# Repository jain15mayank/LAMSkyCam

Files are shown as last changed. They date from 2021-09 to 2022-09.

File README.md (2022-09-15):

# LAMSkyCam: A Low-cost and Miniature Ground-based Sky Camera

With the spirit of reproducible research, this repository contains all the codes and materials required to make the hardware in the manuscript:

> Jain, M., Sengar, V. S., Gollini, I., Bertolotto, M., McArdle, G., and Dev, S.(2022). LAMSkyCam: A Low-cost and Miniature Ground-based Sky Camera. In: HardwareX, 2022.

Please cite the above paper if you intend to use whole/part of the code. This code is only for academic and research purposes.

## Manuscript
The manuscript can be accessed from [this](https://arxiv.org/pdf/2209.06051.pdf) link.

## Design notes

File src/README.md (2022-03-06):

This folder contains the source code to manage external memory and capture images from the camera. Other aspects like maintaining the running status of `manageHDD_cron.py` and executing `cameraSave_cron.py` at regular intervals is managed by adding cronjobs in RaspberryPi OS.

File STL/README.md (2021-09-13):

This directory contains the STL files for rapid prototyping of the existing design of the WSI.

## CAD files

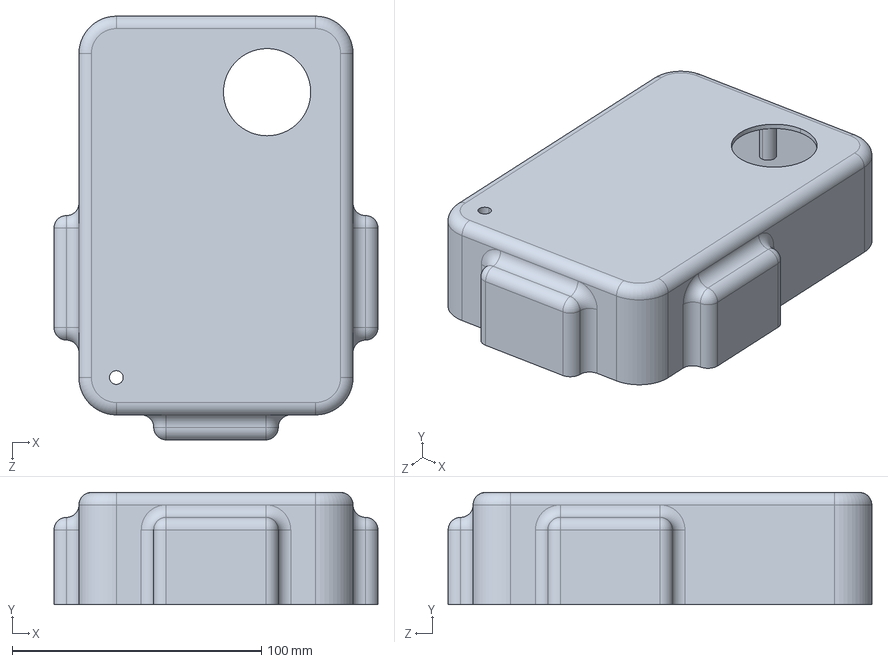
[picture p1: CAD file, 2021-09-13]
STEP/Part #01.STEP
130.0 x 45.0 x 170.0 mm

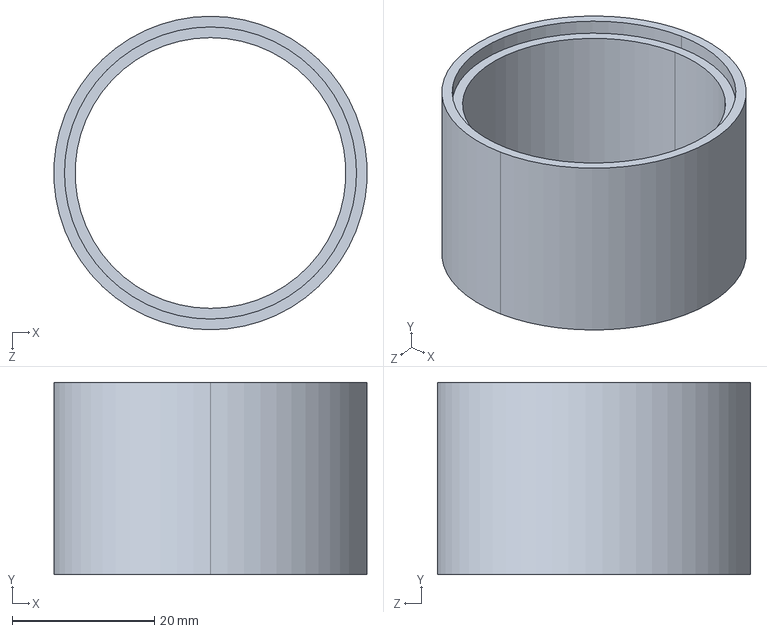
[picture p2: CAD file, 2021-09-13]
STEP/Part #07.STEP
43.9 x 27.0 x 44.0 mm

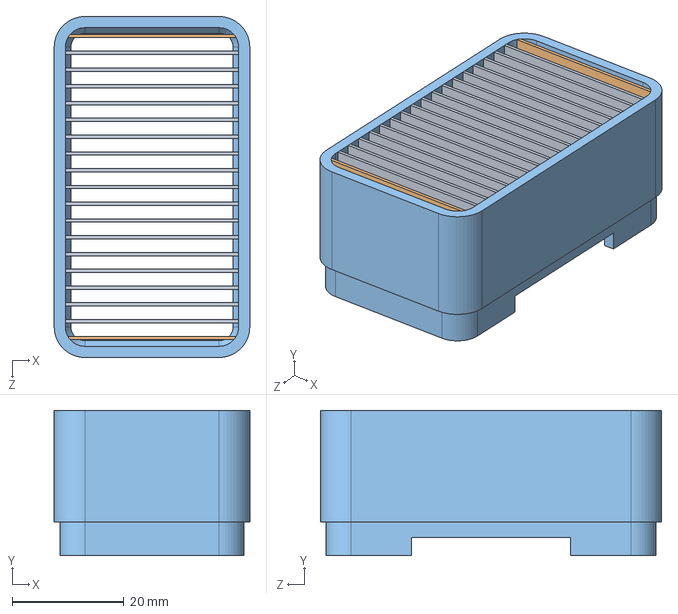
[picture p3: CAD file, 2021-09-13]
STEP/Part #03.STEP
35.0 x 26.0 x 61.0 mm

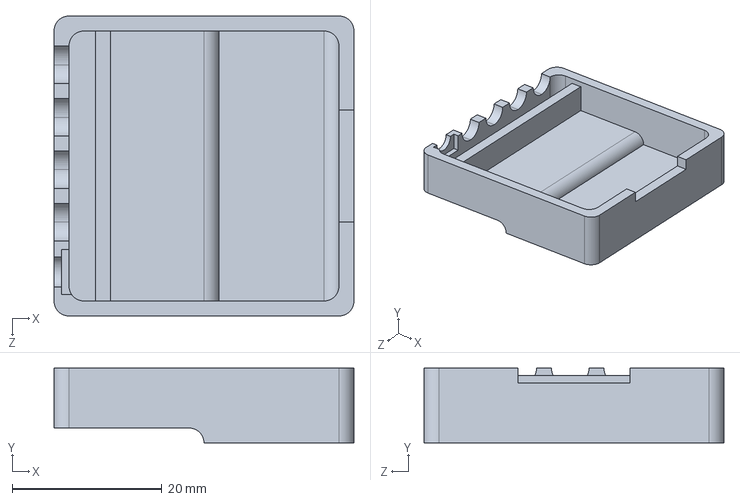
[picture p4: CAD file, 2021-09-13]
STEP/Part #09.STEP
40.0 x 10.0 x 40.0 mm

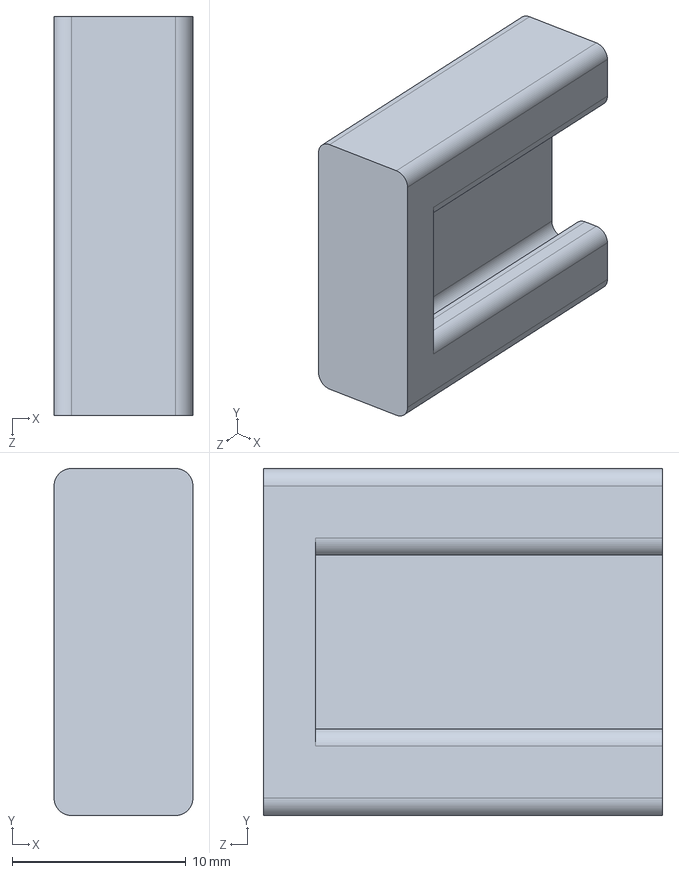
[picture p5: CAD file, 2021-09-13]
STEP/Part #05.STEP
8.00 x 20.0 x 23.0 mm

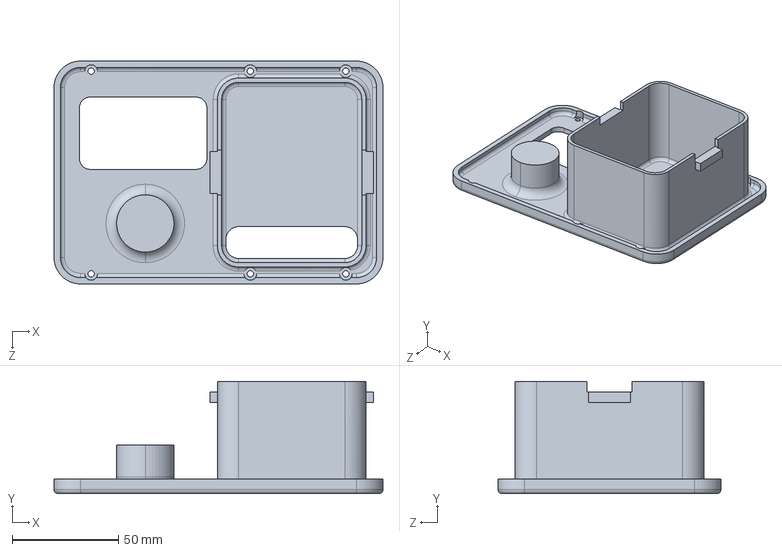
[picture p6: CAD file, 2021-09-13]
STEP/Part #02.STEP
155.0 x 53.0 x 105.0 mm

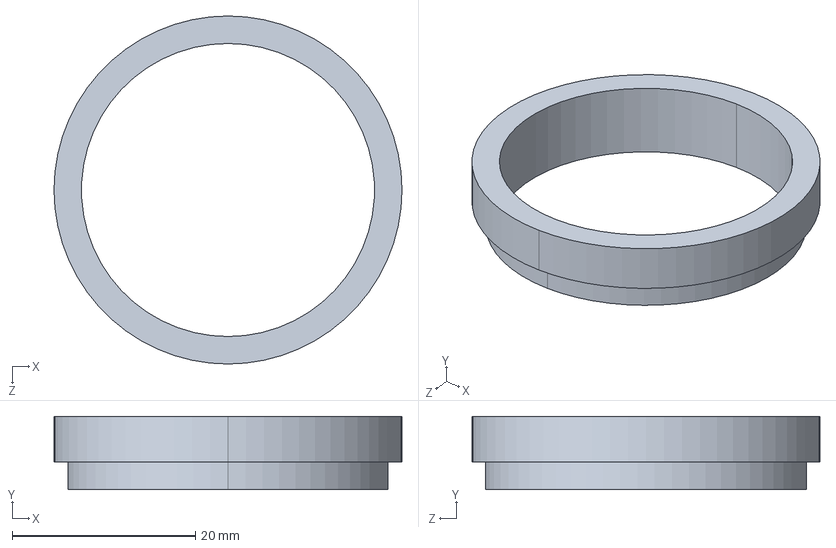
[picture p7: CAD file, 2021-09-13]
STEP/Part #06.STEP
38.0 x 8.00 x 38.0 mm

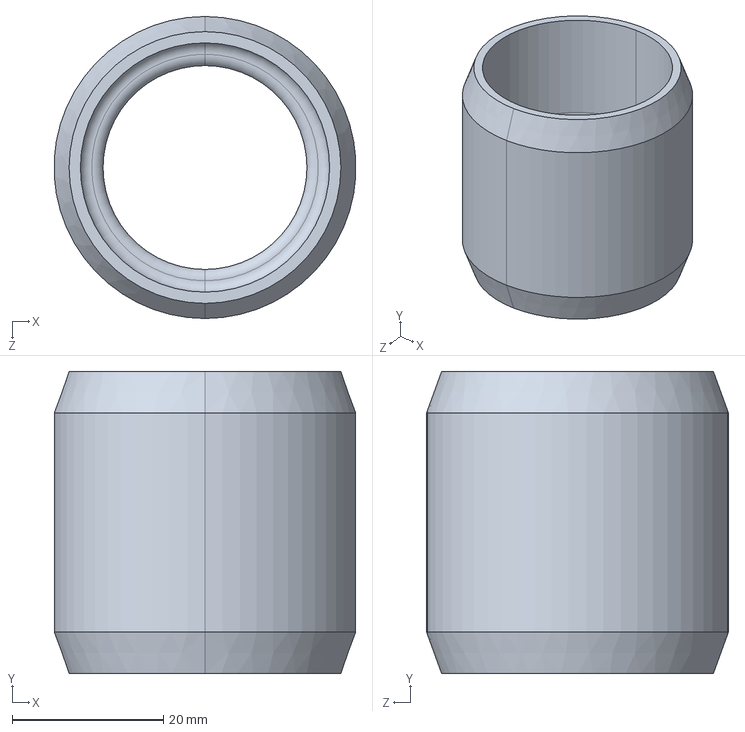
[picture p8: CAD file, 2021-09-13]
STEP/Part #11.STEP
39.9 x 40.0 x 40.0 mm

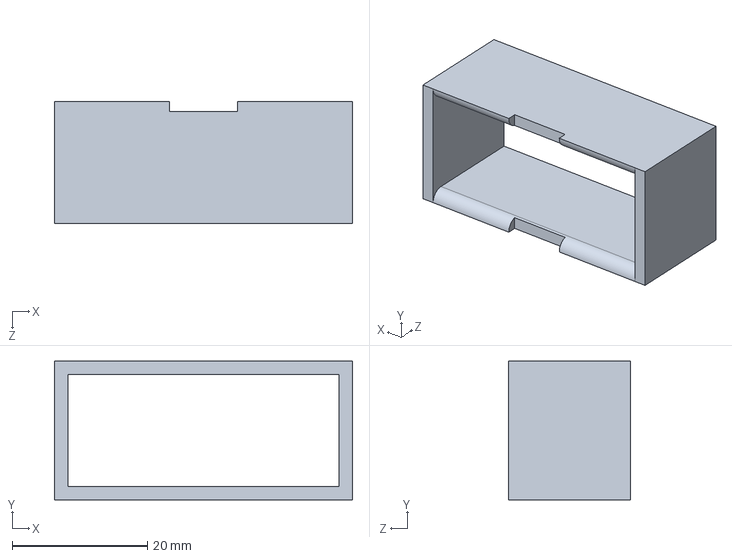
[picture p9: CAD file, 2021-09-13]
STEP/Part #10.STEP
44.0 x 20.5 x 18.0 mm

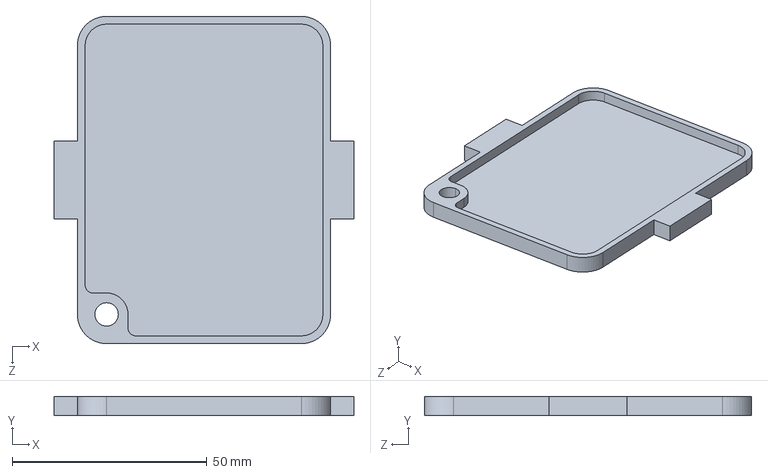
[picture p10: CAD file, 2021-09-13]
STEP/Part #04.STEP
77.0 x 5.00 x 84.0 mm

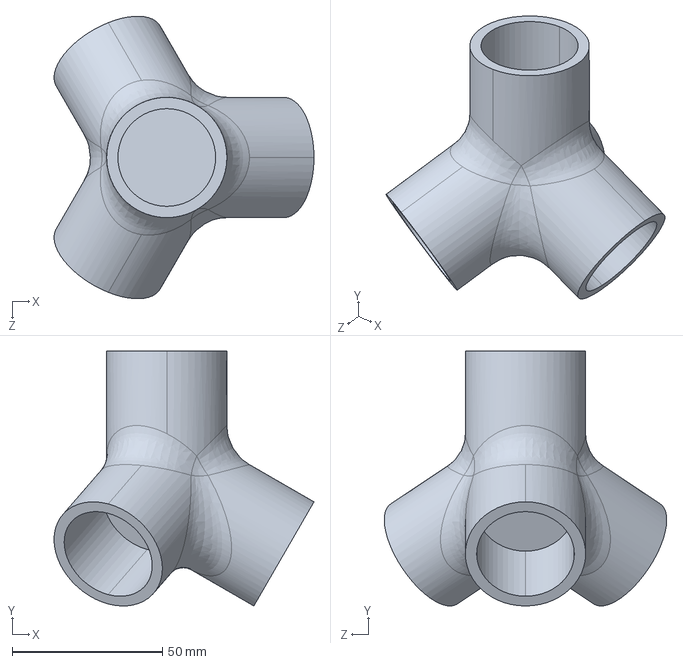
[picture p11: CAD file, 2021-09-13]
STEP/Part #12.STEP
86.5 x 84.8 x 93.9 mm

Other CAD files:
STEP/Part #08.STEP
STL/Part #01.STL
STL/Part #02.STL
STL/Part #03.STL
STL/Part #04.STL
STL/Part #05.STL
STL/Part #06.STL
STL/Part #07.STL
STL/Part #08.STL
STL/Part #09.STL
STL/Part #10.STL
STL/Part #11.STL
STL/Part #12.STL

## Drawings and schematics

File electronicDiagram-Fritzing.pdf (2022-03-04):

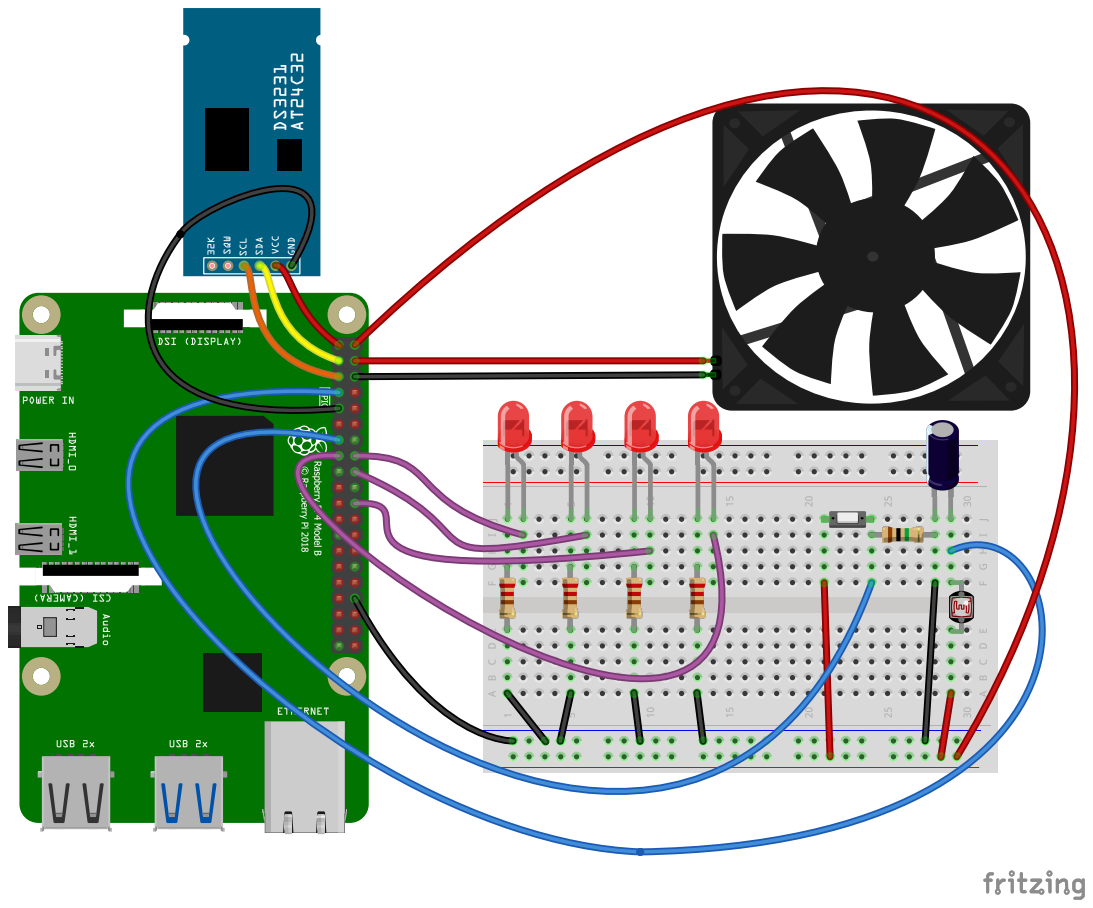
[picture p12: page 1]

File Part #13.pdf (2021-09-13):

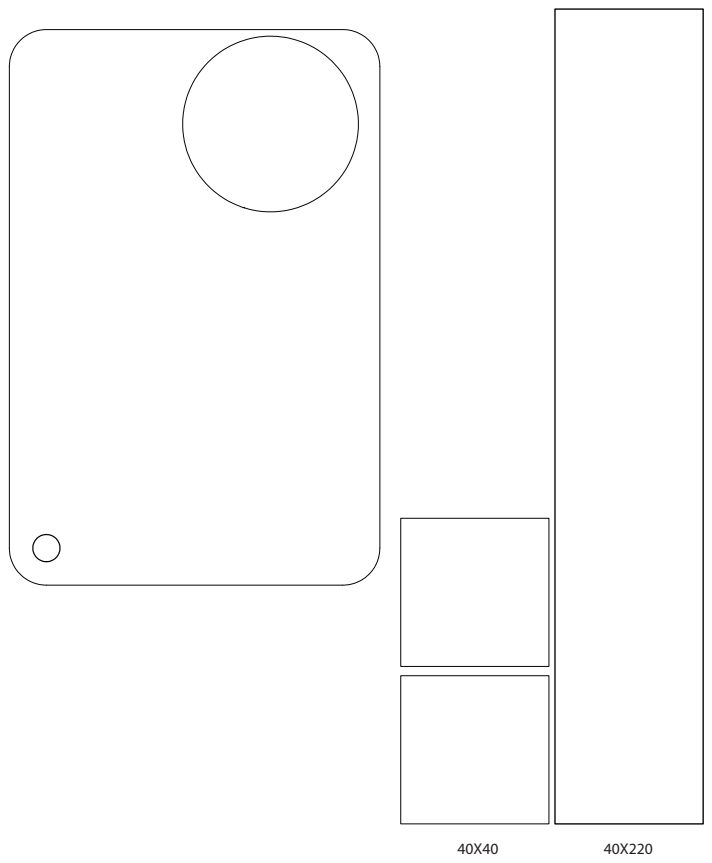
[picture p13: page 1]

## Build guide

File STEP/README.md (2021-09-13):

This directory contains the design files in STEP (ISO 10303) format for easy reproducibility and customization. All the parts have been individually discussed in detail in the published manuscript.

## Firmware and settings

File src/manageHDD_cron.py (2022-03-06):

#!/usr/bin/env python3

import os
import subprocess
import RPi.GPIO as GPIO    # Import Raspberry Pi GPIO library
from time import time, localtime, sleep
from utils import checkHDDstatus
from utils import SD2HD

# Determine the PID of current process
pid = str(os.getpid())
# Define path to the pidfile
pidfile = '/tmp/WSI_HDD_daemon.pid'
# Write the PID to that file
f = open(pidfile, "w")
f.write(pid)
f.close()

# Label/Name of the Hard disk where final data will be stored
HDlabel = 'Seagate Expansion Drive'

# Path where images will be stored
imageDirHD = '/media/pi/'+HDlabel+'/Mayank/WSI/images/'
imageDirSD = '/home/pi/Pictures/'

logsHDDpath = '/home/pi/Desktop/WSIwork/HDDlogs'

log_time = localtime(time())
timeSTR = str(log_time.tm_year)+'/' + \
          str(log_time.tm_mon)+'/' + \
          str(log_time.tm_mday)+' ' + \
          str(log_time.tm_hour)+':' + \
          str(log_time.tm_min)+':' + \
          str(log_time.tm_sec)
logsHDD = open(logsHDDpath, 'a')
logsHDD.write(timeSTR + " - HDD File started with PID: " + pid + "\n")
logsHDD.close()

GPIO.setwarnings(False)    # Ignore warnings for now
GPIO.setmode(GPIO.BCM)     # Use GPIO pin numbering

# Declare Peripherals
LED1 = 22 # Button Press Detected
LED2 = 23 # Removing Hard Disk Completed
LED3 = 24 # Hard Disk detected Once Again
LED4 = 25 # Writing data to disk - notification LED
PBut = 27

# Set all LEDs to OUTPUT and initialize to LOW
GPIO.setup(LED1, GPIO.OUT, initial=GPIO.LOW)
GPIO.setup(LED2, GPIO.OUT, initial=GPIO.LOW)
GPIO.setup(LED3, GPIO.OUT, initial=GPIO.LOW)
GPIO.setup(LED4, GPIO.OUT, initial=GPIO.LOW)
# Set Push Button to INPUT
GPIO.setup(PBut, GPIO.IN)

# Define Unmount Flag :: True = HDD unmounted; False = HDD mounted
if checkHDDstatus(HDlabel): # HDD is mounted
    isUnmounted = False
    log_time = localtime(time())
    timeSTR = str(log_time.tm_year)+'/' + \
              str(log_time.tm_mon)+'/' + \
              str(log_time.tm_mday)+' ' + \
              str(log_time.tm_hour)+':' + \
              str(log_time.tm_min)+':' + \
              str(log_time.tm_sec)
    logsHDD = open(logsHDDpath, 'a')
    logsHDD.write(timeSTR + " - HDD is detected INITIALLY!\n")
    logsHDD.close()
else:
    isUnmounted = True
    log_time = localtime(time())
    timeSTR = str(log_time.tm_year)+'/' + \
              str(log_time.tm_mon)+'/' + \
              str(log_time.tm_mday)+' ' + \
              str(log_time.tm_hour)+':' + \
              str(log_time.tm_min)+':' + \
              str(log_time.tm_sec)
    logsHDD = open(logsHDDpath, 'a')
    logsHDD.write(timeSTR + " - HDD is NOT detected INITIALLY!\n")
    logsHDD.close()

# Define Callback for Push Button Interrupt
def button_pressed(channel):
    global isUnmounted
    print('Button Pressed!!')
    log_time = localtime(time())
    timeSTR = str(log_time.tm_year)+'/' + \
              str(log_time.tm_mon)+'/' + \
              str(log_time.tm_mday)+' ' + \
              str(log_time.tm_hour)+':' + \
              str(log_time.tm_min)+':' + \
              str(log_time.tm_sec)
    logsHDD = open(logsHDDpath, 'a')
    logsHDD.write(timeSTR + " - Button Press Detected\n")
    logsHDD.close()
    # Turn on to indicate detection button press
    GPIO.output(LED1, GPIO.HIGH)
    if checkHDDstatus(HDlabel): # HDD is mounted
        subprocess.call("sudo umount -t fuseblk /dev/sda1", shell=True)
        isUnmounted = True
        # Turn on to indicate successful unmount
        GPIO.output(LED2, GPIO.HIGH)
        sleep(5)
        GPIO.output(LED2, GPIO.LOW)
        sleep(1)
    GPIO.output(LED1, GPIO.LOW)
    log_time = localtime(time())
    timeSTR = str(log_time.tm_year)+'/' + \
              str(log_time.tm_mon)+'/' + \
              str(log_time.tm_mday)+' ' + \
              str(log_time.tm_hour)+':' + \
              str(log_time.tm_min)+':' + \
              str(log_time.tm_sec)
    logsHDD = open(logsHDDpath, 'a')
    logsHDD.write(timeSTR + " - HDD Unmounting routine successful!\n")
    logsHDD.close()

# Define event of pressing Push Button as Interrupt (debounce time in ms)
GPIO.add_event_detect(PBut, GPIO.RISING,\
                      callback = button_pressed, bouncetime = 10000)

# Main Code Statrts Here
prevHr = localtime(time()).tm_hour
while True: # Run Forever
    currHr = localtime(time()).tm_hour
    if (not currHr == prevHr) and (currHr == 0 or currHr==12) and (not isUnmounted):
        log_time = localtime(time())
        timeSTR = str(log_time.tm_year)+'/' + \
                  str(log_time.tm_mon)+'/' + \
                  str(log_time.tm_mday)+' ' + \
                  str(log_time.tm_hour)+':' + \
                  str(log_time.tm_min)+':' + \
                  str(log_time.tm_sec)
        logsHDD = open(logsHDDpath, 'a')
        logsHDD.write(timeSTR + " - Conditions for Writing Data MET - Writing to HDD...\n")
        logsHDD.close()
        # Begin transferring data to HDD
        GPIO.output(LED4, GPIO.HIGH)
        SD2HD(imageDirSD, imageDirHD)
        GPIO.output(LED4, GPIO.LOW)
        # End transferring data to HDD
        log_time = localtime(time())
        timeSTR = str(log_time.tm_year)+'/' + \
                  str(log_time.tm_mon)+'/' + \
                  str(log_time.tm_mday)+' ' + \
                  str(log_time.tm_hour)+':' + \
                  str(log_time.tm_min)+':' + \
                  str(log_time.tm_sec)
        logsHDD = open(logsHDDpath, 'a')
        logsHDD.write(timeSTR + " - Writing to HDD successful!\n")
        logsHDD.close()
        prevHr = currHr
    else:
        temp = localtime(time()).tm_hour
        if not (temp==0 or temp==12):
            prevHr = temp
        if checkHDDstatus(HDlabel) and isUnmounted:
            log_time = localtime(time())
            timeSTR = str(log_time.tm_year)+'/' + \
                      str(log_time.tm_mon)+'/' + \
                      str(log_time.tm_mday)+' ' + \
                      str(log_time.tm_hour)+':' + \
                      str(log_time.tm_min)+':' + \
                      str(log_time.tm_sec)
            logsHDD = open(logsHDDpath, 'a')
            logsHDD.write(timeSTR + " - HDD Redected!\n")
            logsHDD.close()
            isUnmounted = False
            # Turn on LED3 for 5 seconds to indicate HDD detection
            GPIO.output(LED3, GPIO.HIGH)
            sleep(5)
            GPIO.output(LED3, GPIO.LOW)

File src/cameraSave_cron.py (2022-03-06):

#!/usr/bin/env python3

from utils import captureNsave
import RPi.GPIO as GPIO
from time import sleep, time, localtime
import subprocess
from pathlib import Path

GPIO.setwarnings(False)    # Ignore warnings for now
GPIO.setmode(GPIO.BCM)     # Use GPIO pin numbering

# Declare Peripherals
LDR = 4 # LDR Connected Here

imageDirSD = '/home/pi/Pictures/'

# Function to check LDR Reading
def rc_time (pin_to_circuit):
    for i in range(5):
        count = 0
        
        #Output LOW on the pin for 0.1 seconds
        GPIO.setup(pin_to_circuit, GPIO.OUT)
        GPIO.output(pin_to_circuit, GPIO.LOW)
        sleep(0.1)
        
        #Change the pin back to input
        GPIO.setup(pin_to_circuit, GPIO.IN)
      
        #Count until the pin goes high
        while (GPIO.input(pin_to_circuit) == GPIO.LOW):
            count += 1
        sleep(0.1)
    
    return count/5

curr_time = localtime(time())
timeSTR = str(curr_time.tm_year)+'/' + \
          str(curr_time.tm_mon)+'/' + \
          str(curr_time.tm_mday)+' ' + \
          str(curr_time.tm_hour)+':' + \
          str(curr_time.tm_min)+':' + \
          str(curr_time.tm_sec)
fLogs = open("/home/pi/Desktop/WSIwork/logs", "a")
fLogs.write(timeSTR + " - Capture Begin...\n")
fLogs.close()

imagePath = imageDirSD + str(curr_time.tm_year)+'/' + \
            str(curr_time.tm_mon)+'/' + \
            str(curr_time.tm_mday)+'/'
hh = "{0:0=2d}".format(curr_time.tm_hour)
mm = "{0:0=2d}".format(curr_time.tm_min)
ss = "{0:0=2d}".format(curr_time.tm_sec)
Path(imagePath).mkdir(parents=True, exist_ok=True)
#if curr_time.tm_hour>=19 or curr_time.tm_hour<5:
rcTime = rc_time(LDR)
curr_time = localtime(time())
timeSTR = str(curr_time.tm_year)+'/' + \
          str(curr_time.tm_mon)+'/' + \
          str(curr_time.tm_mday)+' ' + \
          str(curr_time.tm_hour)+':' + \
          str(curr_time.tm_min)+':' + \
          str(curr_time.tm_sec)
fLogs = open("/home/pi/Desktop/WSIwork/logs", "a")
fLogs.write(timeSTR + " - Value of rcTime is " + str(rcTime) + "\n")
fLogs.close()
if rcTime>100:
    subprocess.call("raspistill -md 3 -drc high -ex night -ss 2500000 -o " +imagePath+hh+mm+ss+".png", shell=True)
elif rcTime<50:
    subprocess.call("raspistill -md 3 -o " +imagePath+hh+mm+ss+".png", shell=True)
else:
    subprocess.call("raspistill -md 3 -drc med -ex night -ss 1500000 -o " +imagePath+hh+mm+ss+".png", shell=True)
#captureNsave(imageDirSD)

curr_time = localtime(time())
timeSTR = str(curr_time.tm_year)+'/' + \
          str(curr_time.tm_mon)+'/' + \
          str(curr_time.tm_mday)+' ' + \
          str(curr_time.tm_hour)+':' + \
          str(curr_time.tm_min)+':' + \
          str(curr_time.tm_sec)
fLogs = open("/home/pi/Desktop/WSIwork/logs", "a")
fLogs.write(timeSTR + " - Capture and Save Completed\n")
fLogs.close()

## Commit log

2021-09-13 Uploaded Design Files
    [AccessLid.STEP, Cover.STEP, Duct.STEP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]
2021-09-13 Files Uploaded
    [2XLidRetainer.STL, Cover 4.STL, Duct.STL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]
2021-09-13 deleted step dir
    [AccessLid.STEP, Cover.STEP, Duct.STEP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]
2021-09-13 Design Files Uploaded
    [Duct.STEP, LensHood.STEP, LensHoodMount.STEP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]
2021-09-13 deleted STL dir
    [2XLidRetainer.STL, Cover 4.STL, Duct.STL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]
2021-09-13 Uploaded STL Files
    [Duct.STL, LensHood.STL, LensHoodMount.STL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]
2021-09-13 STL Files Uploaded
    [Part #01.STL, Part #02.STL, Part #03.STL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]
2021-09-13 Insulation Sheet Cut Measurements
